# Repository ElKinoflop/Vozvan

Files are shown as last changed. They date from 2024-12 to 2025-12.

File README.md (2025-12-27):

# Vozvan
Stacked acrylic, handwired, monobody split, 12.75u, 40% keyboard

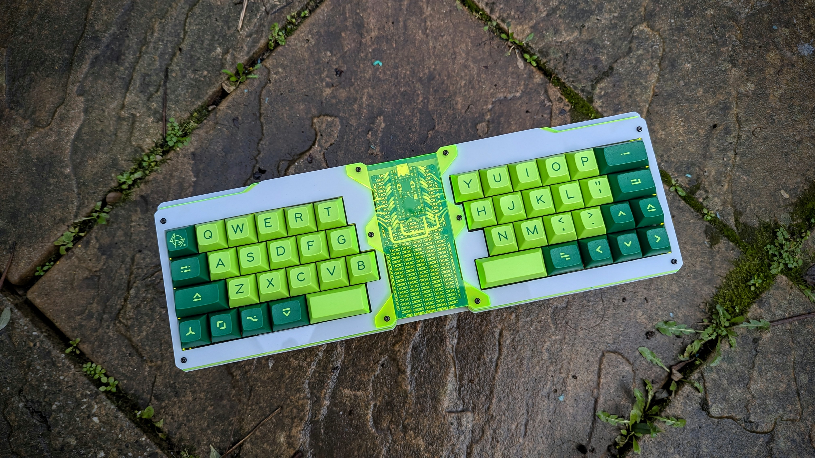
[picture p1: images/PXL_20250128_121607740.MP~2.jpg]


Vozvan Keyboard Photo

Stacked acrylic keyboard case designed for handwiring with a <a href="https://mechboards.co.uk/products/pro-micro-5v?_pos=2&_sid=c64ff0323&_ss=r" target="_blank">Pro Micro footprint RP2040 controller</a>. 12.75u layout monobody split. Inspired by Peej's <a href="https://github.com/peej/lumberjack-keyboard" target="_blank">Lumberjack</a>, SquashKB's <a href="https://www.instagram.com/squash_kb/?hl=en-gb">Lesovoz</a>, Trashman's <a href="https://trashman.wiki/keyboards/v4n4g0n">V4N4G0N/Minivan</a> and <a href="https://p3dstore.notion.site/P3Dstore-Open-Source-Project-List-6e85900337294e769fb7b8fa68d68f27">Jake/P3D's acrylic cases</a>. The idea was to use all off the shelf components (other than the case). There are lots of options on what you could do with the central section such as encoders, tactile push buttons, LEDs or an OLED display. Different proto board mounts and either a straight or V shape can be accomodated by changing some of the layers.

Feel free to do whatever you want with the files. If you have any questions just ask (Discord username elkinoflop) and if you make one then share a photo with me!

<h1>Layout</h1>
There are two different layouts. A stabless version and a version which requires 2x plate mounted 2u stabs. They both have the same amount of keys so your choice of layout doesn't change the matrix.

<h2>Stabless</h2>
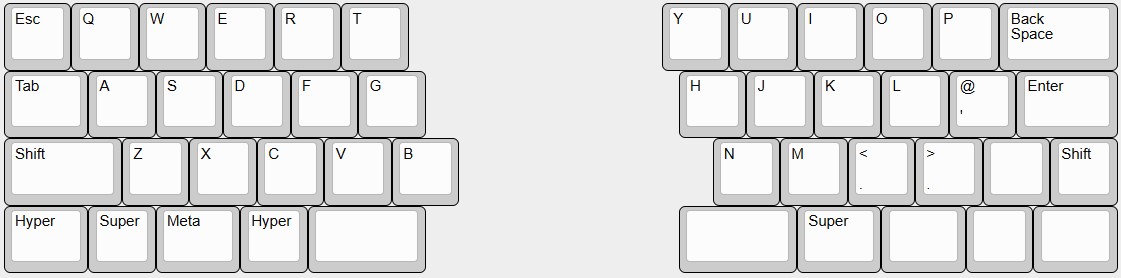
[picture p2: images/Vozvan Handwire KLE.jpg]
Vozvan Stabless KLE Image


<h2>Stabbed</h2>
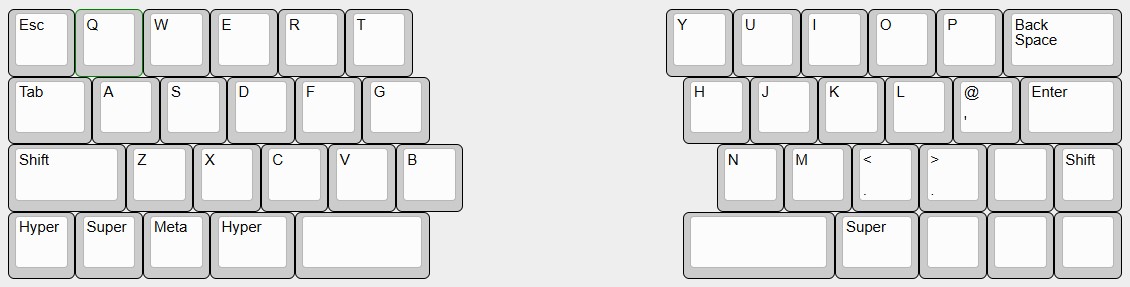
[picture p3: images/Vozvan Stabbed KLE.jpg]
Vozvan Stabbed KLE Image


<h1>KLE Raw Data</h1>
<h2>Stabless</h2>
["Esc","Q","W","E","R","T",{x:3.75},"Y","U","I","O","P",{w:1.75},"Back<br>Space"],
[{w:1.25},"Tab","A","S","D","F","G",{x:3.75},"H","J","K","L","@\n'",{w:1.5},"Enter"],
[{w:1.75},"Shift","Z","X","C","V","B",{x:3.75},"N","M","<\n.",">\n.",{a:7},"",{a:4},"Shift"],
[{w:1.25},"Hyper","Super",{w:1.25},"Meta","Hyper",{a:7,w:1.75},"",{x:3.75,w:1.75},"",{a:4,w:1.25},"Super",{a:7,w:1.25},"","",{w:1.25},""]

<h2>Stabbed</h2>
["Esc","Q","W","E","R","T",{x:3.75},"Y","U","I","O","P",{w:1.75},"Back<br>Space"],
[{w:1.25},"Tab","A","S","D","F","G",{x:3.75},"H","J","K","L","@\n'",{w:1.5},"Enter"],
[{w:1.75},"Shift","Z","X","C","V","B",{x:3.75},"N","M","<\n.",">\n.",{a:7},"",{a:4},"Shift"],
["Hyper","Super","Meta",{w:1.25},"Hyper",{a:7,w:2},"",{x:3.75,w:2.25},"",{a:4,w:1.25},"Super",{a:7},"","",""]

<h1>Case variants</h1>
<li>There are different variations of the case. Layers 1-7 are common across all variants (except the one piece) but 0 (component cover), 8 (bottom) and 9 (feet) will change depending on which you choose. Currently only the SEC version has been tested. If you do add an encoder or extra buttons in the centre remember to modify the central component cover so that they fit. There are some STL 3D models in the <a href="https://github.com/ElKinoflop/Vozvan/tree/main/images" target="_blank">images folder</a>, these are just to give an alternative visualisation of the case and not designed for printing.</li>
<h3>Standard - ElectroCookie</h3>
Straight board with mounting points for an ElectroCookie protoboard. The specific case files for this variant will have SEC after the layer number

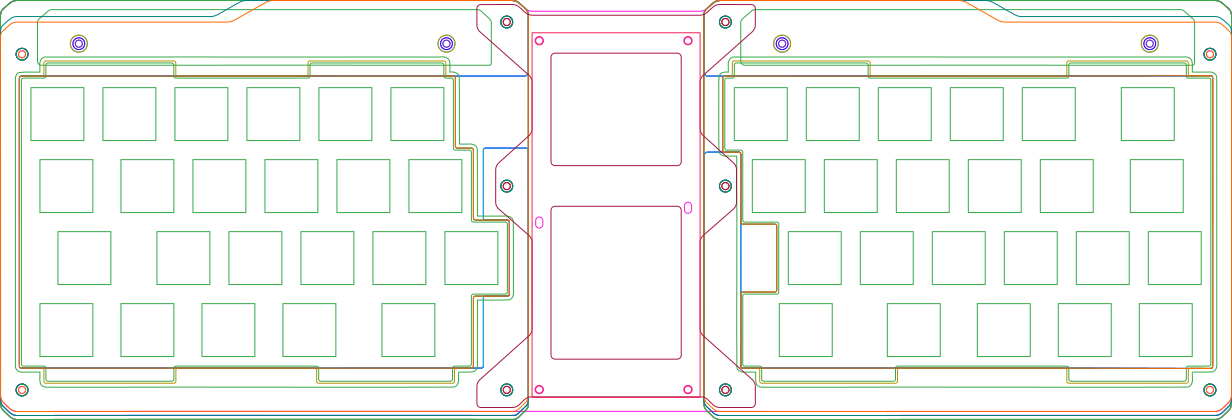
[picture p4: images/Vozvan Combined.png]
Vozvan SEC Case Layers


<h3>Standard - FeatherWing</h3>
Straight board with mounting points for an Adafruit FeatherWing. The specific case files for this variant will have SFW after the layer number

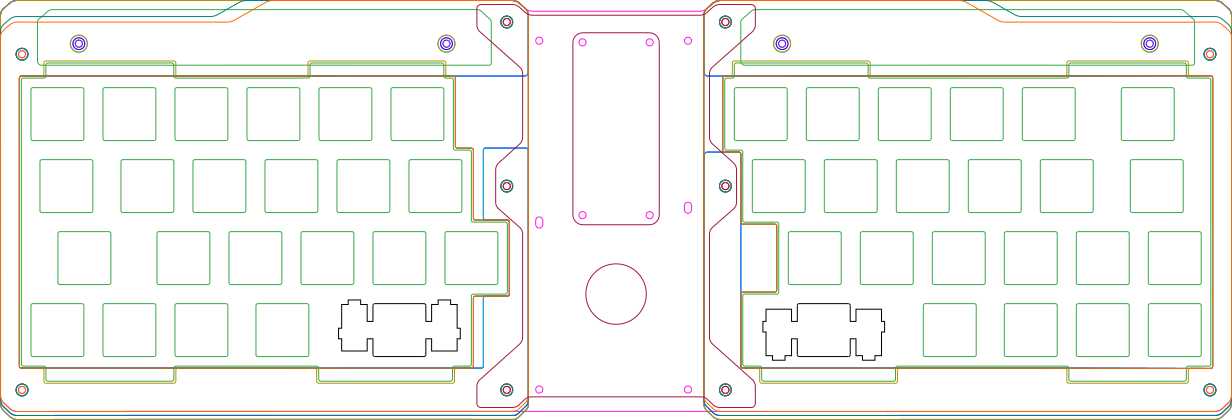
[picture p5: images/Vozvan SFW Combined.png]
Vozvan SFW Case Layers


<h3>5 Degree V - ElectroCookie</h3>
5 Degree V board with mounting points for an ElectroCookie protoboard. The specific case files for this variant will have VEC after the layer number

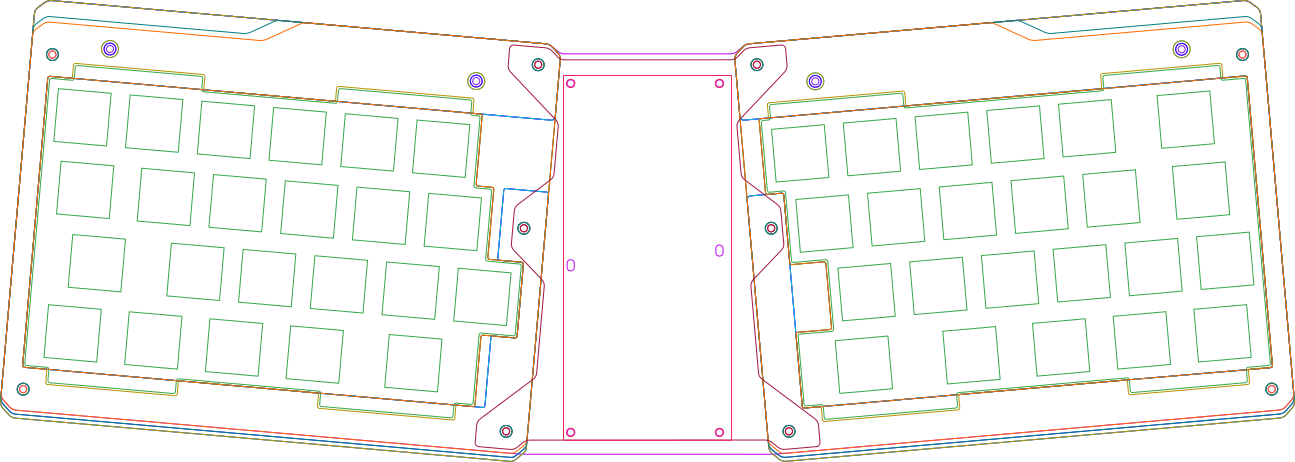
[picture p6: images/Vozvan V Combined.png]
Vozvan VEC Case Layers


<h3>5 Degree V - FeatherWing</h3>
5 Degree V board with mounting points for an Adafruit FeatherWing. The specific case files for this variant will have VFW after the layer number. 'Vozvan 0VFW - Component Cover Button 16mm.dxf' has a cutout designed to be used with an Adafruit NeoPixel FeatherWing and a push button (16mm diameter hole).

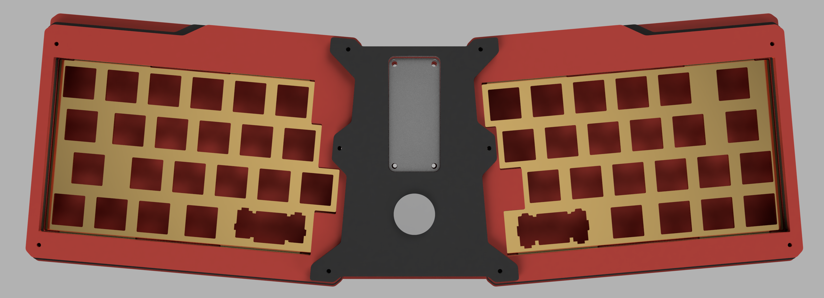
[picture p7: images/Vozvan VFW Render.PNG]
Vozvan VFW Case Render


<h3>One Piece - 5 Degree V - FeatherWing</h3>
A more enclosed variant, 5 Degree V board with mounting points for an Adafruit FeatherWing only. Other than the plates and feet the case parts aren't compatible with the other variants. '0VFWOP - Centre Cover.dxf' has a cutout designed to be used with a push button (16mm diameter hole). You need one of each DXF in the <a href="https://github.com/ElKinoflop/Vozvan/tree/main/Case%20Files/One%20Piece%20VFW" target="_blank">One Piece VFW</a> folder.

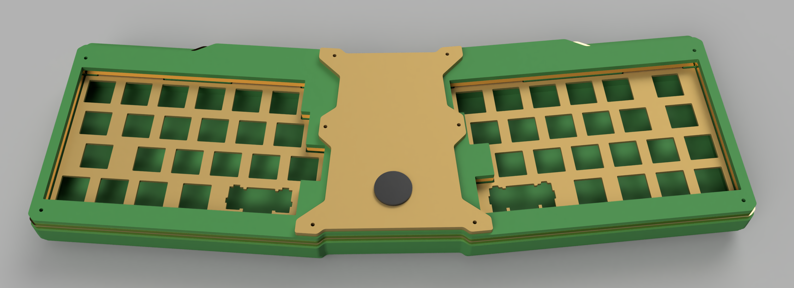
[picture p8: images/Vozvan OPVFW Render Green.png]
Vozvan OPVFW Case Render


<h1>Case Manufacturing</h1>
<ul>
  <li><a href="https://github.com/ElKinoflop/Vozvan/tree/main/Case%20Files" target="_blank">Case files</a></li>
  <li>Designed to be cut from 3mm acrylic</li>
  <li>With the open case layers (5,6 & 7) there is the option of positioning some of the smaller parts (layers 0 or 9) within the open section to save some acrylic but some fabricators might not like doing this.</li>
  <li>Note that acrylic sheets can vary in thickness even if they are listed as 3mm. I have found that Perspex® typically measures at 3-3.1mm whereas Xintao (which most Chinese suppliers seem to use) typically comes in at 2.6-2.7mm. This doesn't matter too much except for your switches will be much more visible with thinner sheets.</li>
  <li>As a rough idea of cost <a href="https://mechboards.co.uk/" target="_blank">Mechboards.co.uk</a> was the best price I could find in the UK at around £80-£90 (inc VAT) for the case and plate. This will vary depending on what acrylic you choose</li>
  <li>Don't force the standoffs through if you find some of the standoffs too tight. Use a small round file if you need to slightly widen any holes. The small round file from Draper 'Soft Grip Needle File Set, 140mm (6 Piece) (83982)' is the perfect size. You shouldn't need to do this but there can be some manufacturing variance.</li>
</ul>

Vozvan Orbit Explosion

<h1>Bill of Materials</h1>
<ul>
  <li>One of each <a href="https://github.com/ElKinoflop/Vozvan/tree/main/Case%20Files" target="_blank">case layer</a> cut from 3mm acrylic. You need one of each number but you don't need for example both 8SEC and 8VEC.</li>
  <li>Either the stabless or stabbed plate DXF file cut from 1.5mm metal/carbon. Flexier/plastic plates aren't recommened as without a PCB you can bottom out the switches on the case and risk the switches popping out of the plate</li>
  <li><a href="https://mechboards.co.uk/products/pro-micro-5v?_pos=2&_sid=c64ff0323&_ss=r" target="_blank">Pro Micro footprint RP2040 controller</a></li>
  <li>M2 Standoffs with a outside diameter of 3mm. 4x 5-6mm for the feet, 10x 12-14mm for the main case, 6x 2-6mm for the proto board mounts. <a href="https://amzn.eu/d/8H1HG6Y" target="_blank">Amazon Standoffs</a></li></li>
  <li>M2 Hex socket button head bolts. Various lengths between 4-12mm. <a href="https://www.aliexpress.com/item/32969042589.html" target="_blank">AliExpress bolts</a></li>
  <li><a href="https://www.amazon.co.uk/dp/B08151V9TS?ref=ppx_yo2ov_dt_b_fed_asin_title" target="_blank">ElectroCookie PCB Prototype Board 3.8"x3.5"</a> OR <a href="https://www.adafruit.com/product/2884" target="_blank">FeatherWing Proto board</a>. Make sure you orient the board correctly before soldering. The ElectroCookie boards aren't symmetrical, the case is designed so the side with the curved corners is on the right (unlike some of the photos)</li>
  <li>Adhesive gasket material. 4mm width. I used 2mm thick gaskets but slightly thinner would be better.</li>
  <li>Wire! Solid core 22 AWG suggested</li>
  <li>46x MX Switches</li>
  <li>46x 1N4148 Diodes (plus any extras if you have buttons/encoders in the middle)</li>
  <li>8x small adhesive feet</li>
  <li>Optional - 2x 2u Plate Mount Stabilisers if you are making the stabbed layout</li>
  <li>Optional - WS2812B LEDs. There's enough pins on the controller to add some RGB if you want. I used two of the <a href="https://www.aliexpress.com/item/1005007273486672.html" target="_blank">5x5 version of these</a>. Placing them under the prototype board gives a nice effect.</li>
  <li>Optional - Rotary Encoder (EC11). There's enough pins on the controller to add and encoder if you want</li>
  <li>Optional - 12*12*7.3mm tactile push button(s). These fit into the breadboard if you want some extra button(s) in the middle</li>
  <li>Optional - <a href="https://www.amazon.co.uk/dp/B08RMQP6YP?ref=ppx_yo2ov_dt_b_fed_asin_title" target="_blank">1.25mm Molex PicoBlade connectors and wire</a>. I used these to connect the matrix to the central section so they can easily be disconnected if required</li>
<li>Optional - <a href="https://learn.adafruit.com/adafruit-neopixel-featherwing" target="_blank">Adafruit NeoPixel FeatherWing</a>. For the VFW variant.</li>
  
</ul>

<h1>Firmware</h1>
I used <a href="https://github.com/JanLunge/pog" target="_blank">POG</a>  to create <a href="https://github.com/KMKfw/kmk_firmware" target="_blank">KMK</a> firmware. POG makes creating firmware super simple but I might create QMK/VIAL firmware at some point!
I have included my firmware files (generated by POG). 

If you have wired up the matrix and connected it to the same controller pins as I have then you should be able to use my firmware. Install <a href="https://circuitpython.org/board/0xcb_helios/" target="_blank">Circuit Python</a> onto the controller first and then copy all the unzipped files from the <a href="https://github.com/ElKinoflop/Vozvan/blob/main/Firmware/Vozvan%20POG%20Firmware.zip" target="_blank">firmware zip</a> onto the drive.

<h1>Handwired Matrix</h1>
This is how I handwired the Matrix.
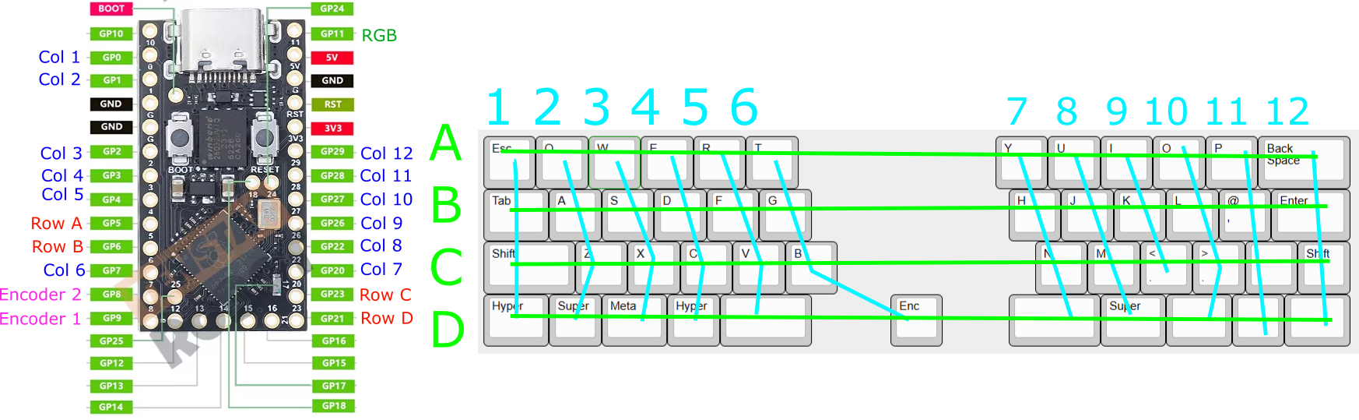
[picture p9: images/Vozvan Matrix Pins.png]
Vozvan Handiwired Matrix


An example of how to wire the proto board for an encoder
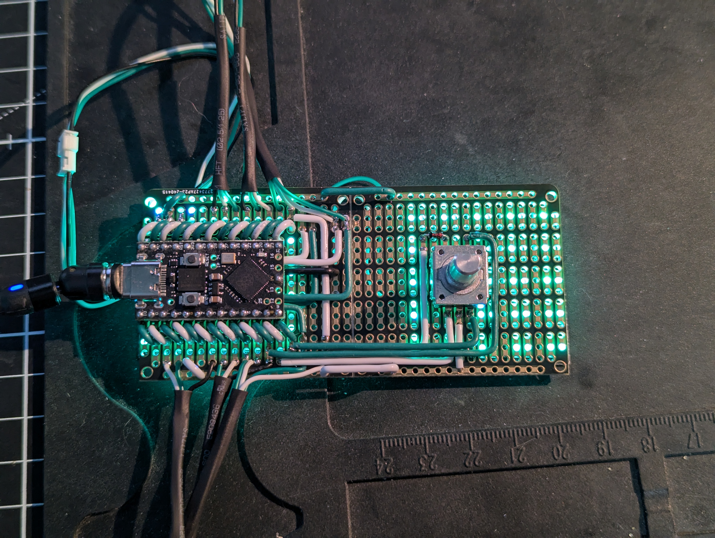
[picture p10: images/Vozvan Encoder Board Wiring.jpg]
Vozvan Encoder Board Wiring


<h1>Disclaimer</h1>
I have made a note of what variants of the case have been tested and which haven't. However you are ordering at your own risk and there are no guarantees that you end up with a functional item. If you do notice any mistakes please contact me (Discord username elkinoflop) so I can fix them.

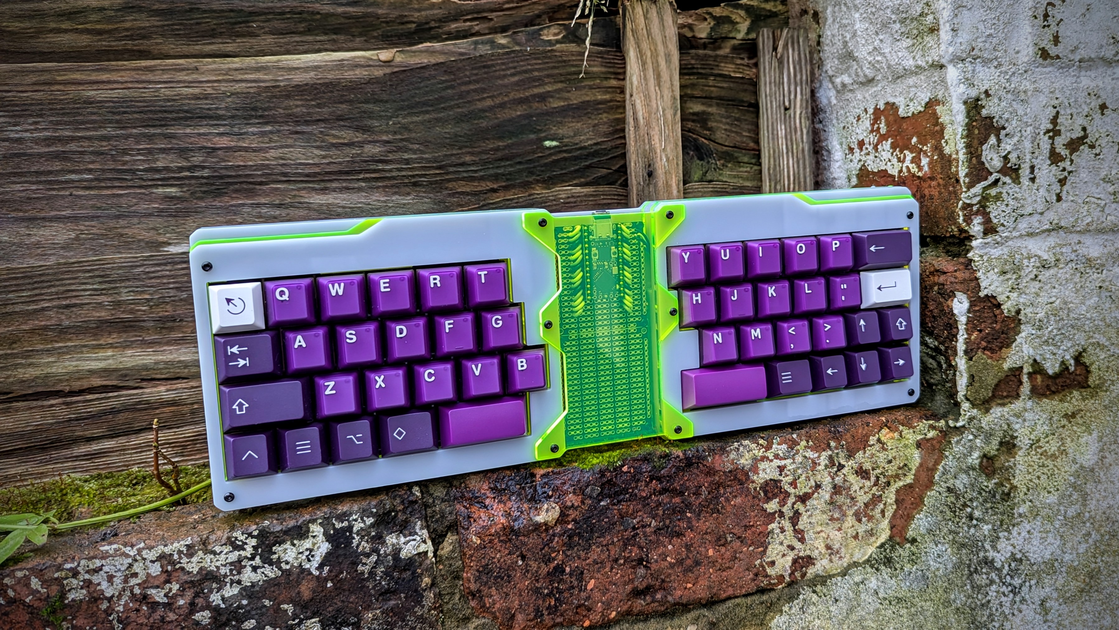
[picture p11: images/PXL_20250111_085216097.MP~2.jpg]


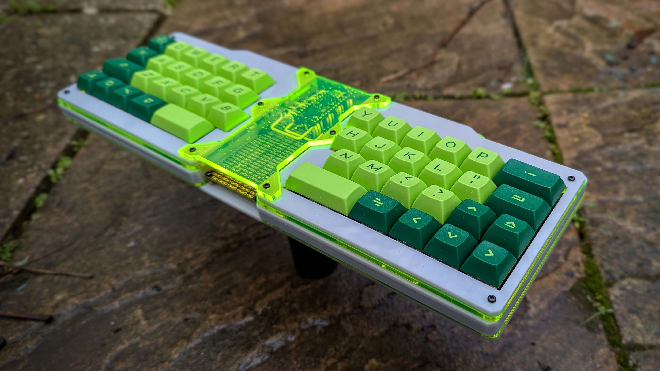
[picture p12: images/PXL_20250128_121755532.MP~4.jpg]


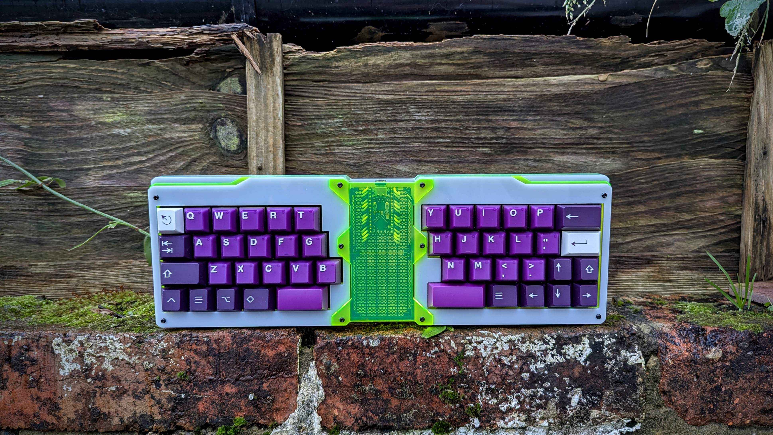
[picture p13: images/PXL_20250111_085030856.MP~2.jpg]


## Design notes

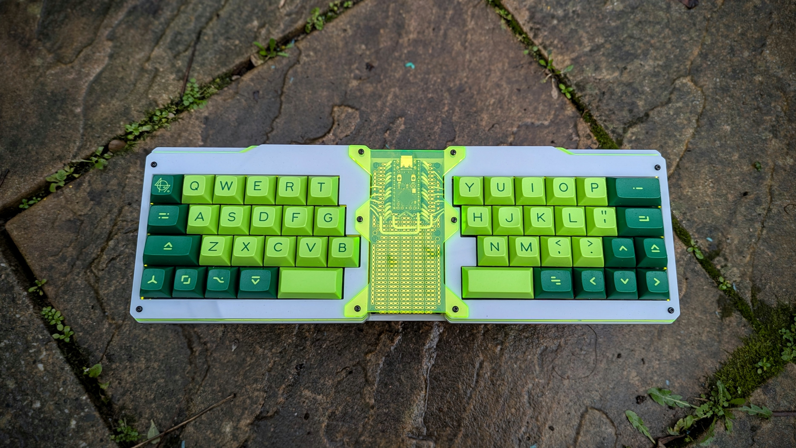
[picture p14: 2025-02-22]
images/PXL_20250128_121633707.MP~2.jpg

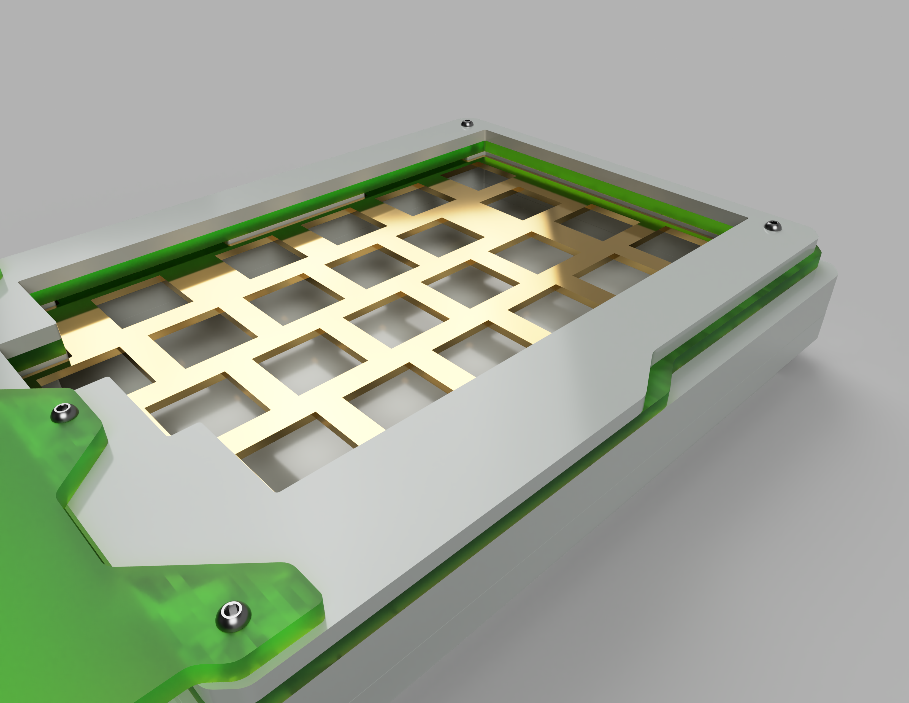
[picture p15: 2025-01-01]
images/9d9e7bed-2c7b-4b43-9d6c-c64e370a0fa1.PNG

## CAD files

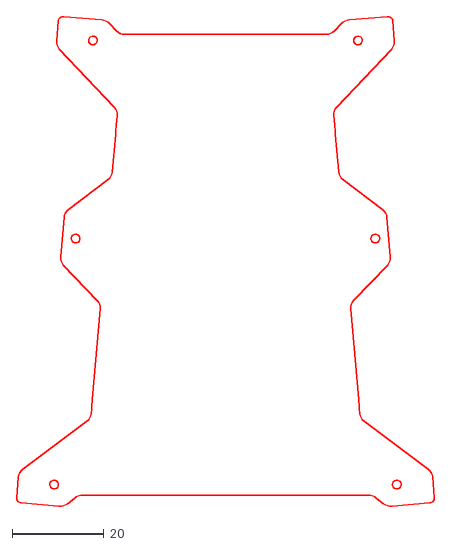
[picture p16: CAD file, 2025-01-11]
Case Files/Vozvan 0VEC 0VFW- Component Cover V Full.dxf
91.3 x 107.0

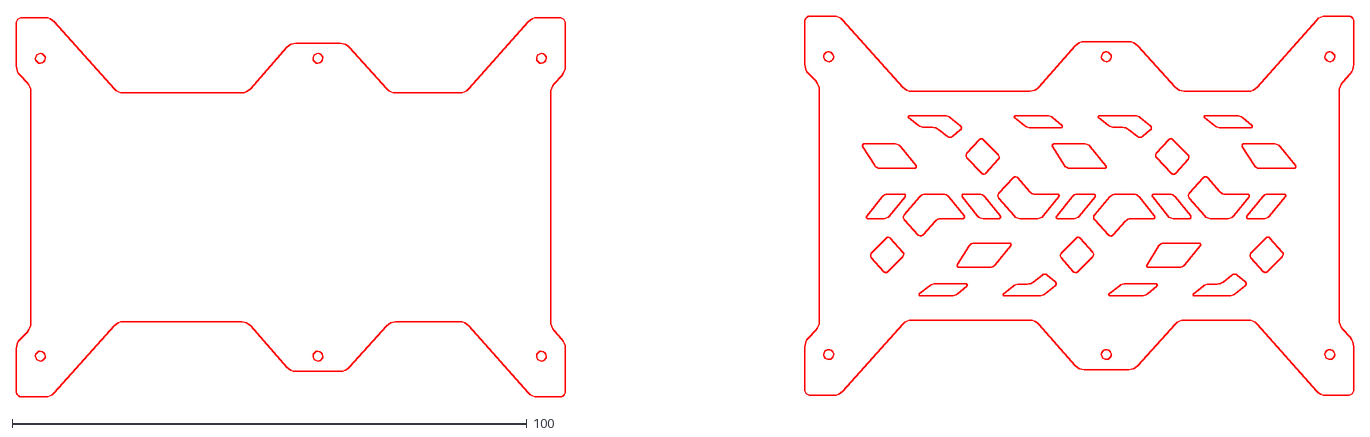
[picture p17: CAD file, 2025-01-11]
Case Files/Vozvan 0SEC 0SFW - Component Covers Full and Cint.dxf
259.8 x 74.0

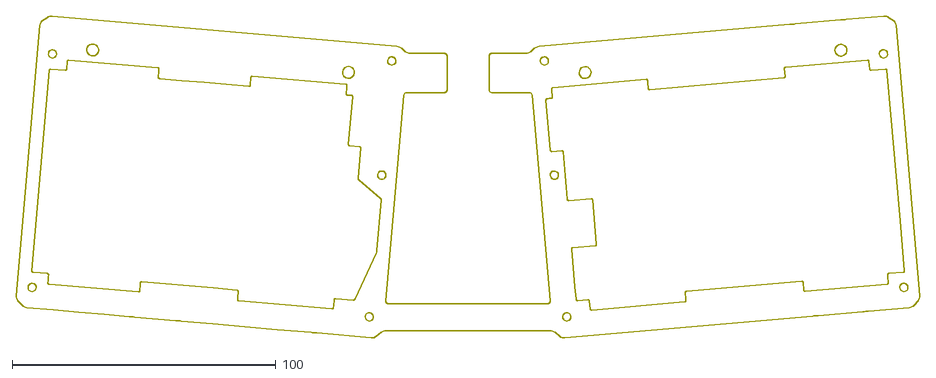
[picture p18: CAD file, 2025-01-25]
Case Files/One Piece VFW/4VFWOP - Plate Layer.dxf
342.4 x 122.0

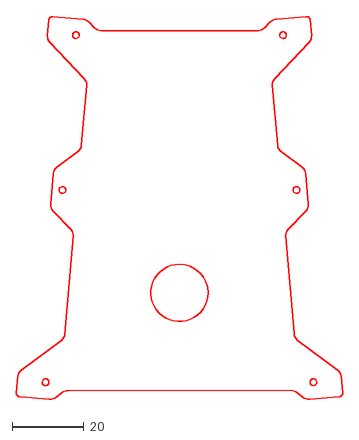
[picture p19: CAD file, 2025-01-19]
Case Files/Vozvan 0VEC 0VFW - Component Cover V Button 16mm.dxf
91.3 x 107.0

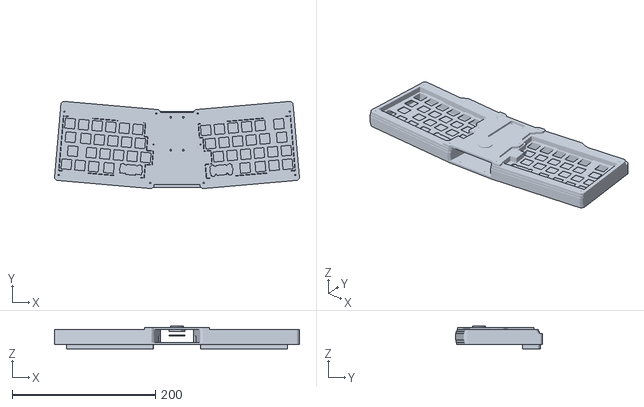
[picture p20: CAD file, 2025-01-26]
images/Vozvan VFW.stl
342.3 x 121.9 x 31.5

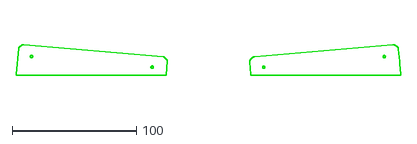
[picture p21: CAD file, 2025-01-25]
Case Files/One Piece VFW/9VFWOP - Foot VFWOP.dxf
309.0 x 24.8

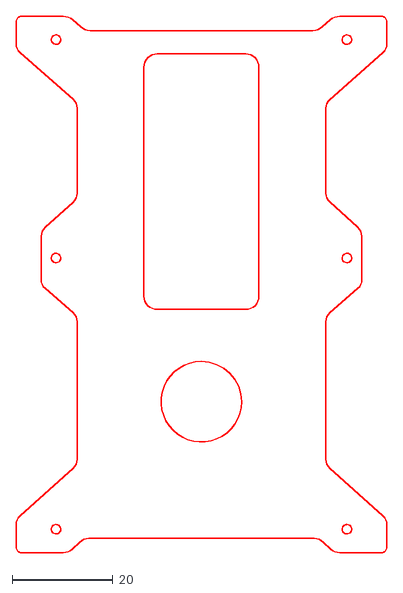
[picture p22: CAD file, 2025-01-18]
Case Files/Vozvan 0SFW - Component Cover FW Button 16mm.dxf
73.7 x 106.6

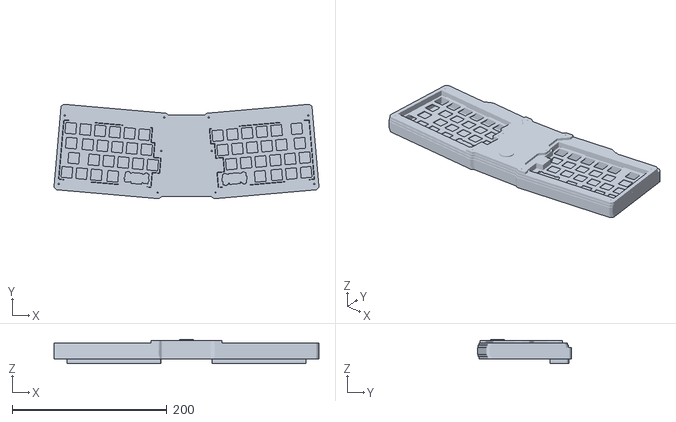
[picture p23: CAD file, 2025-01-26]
images/Vozvan One Piece.stl
342.3 x 121.9 x 31.5

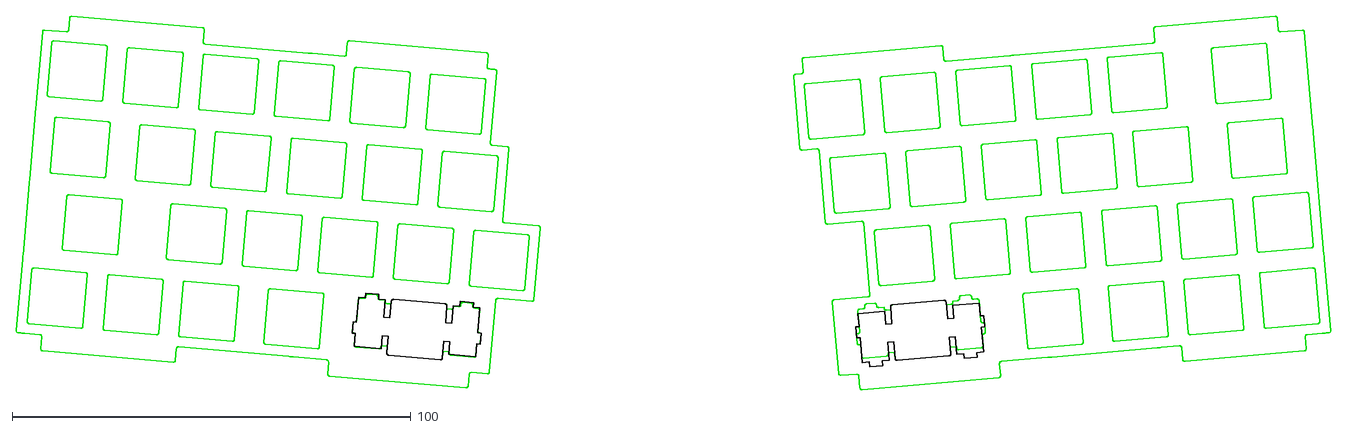
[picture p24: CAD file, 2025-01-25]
Case Files/One Piece VFW/3VFWOP - Plate Stabbed DNU.dxf
329.6 x 93.6

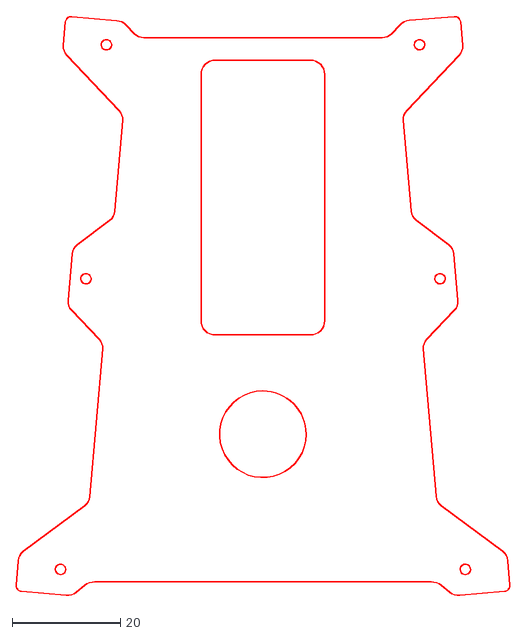
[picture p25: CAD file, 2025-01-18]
Case Files/Vozvan 0VFW - Component Cover Button 16mm.dxf
91.3 x 107.0

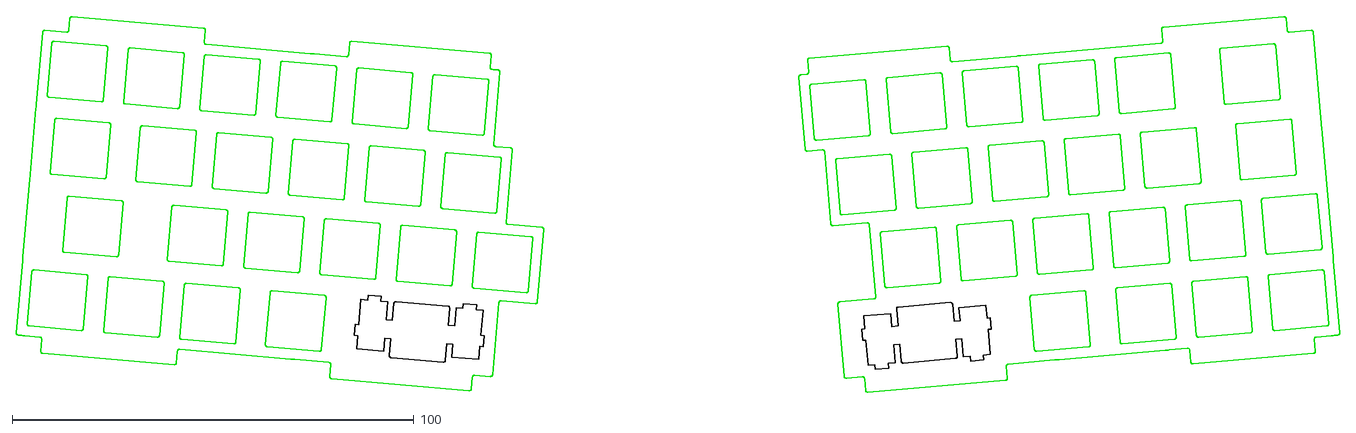
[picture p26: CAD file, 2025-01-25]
Case Files/One Piece VFW/3VFWOP - Plate Stabbed.dxf
329.6 x 93.6

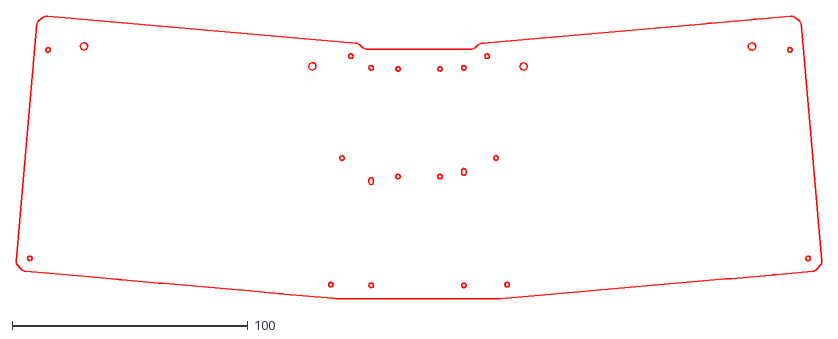
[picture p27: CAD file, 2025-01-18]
Case Files/Vozvan 8VEC 8VFW - Bottom.dxf
342.0 x 120.1

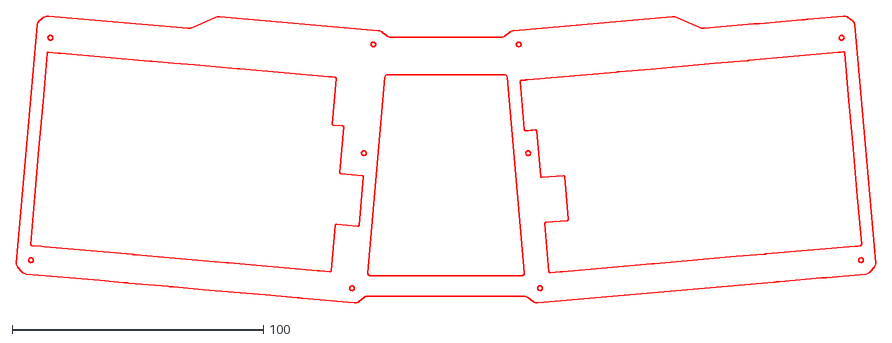
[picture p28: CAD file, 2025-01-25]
Case Files/One Piece VFW/1VFWOP - Top.dxf
342.0 x 114.2

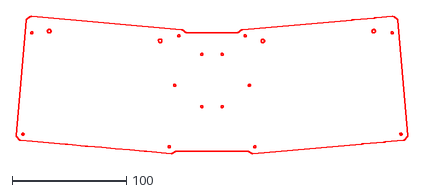
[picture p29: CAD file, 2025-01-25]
Case Files/One Piece VFW/8VFWOP - Bottom VFWOP.dxf
342.0 x 119.9

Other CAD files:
Case Files/Vozvan 2 - Accent.dxf
Case Files/One Piece VFW/0VFWOP - Centre Cover.dxf
Case Files/One Piece VFW/5VFWOP - Mid Upper.dxf
Case Files/One Piece VFW/2VFWOP - Accent.dxf
Case Files/One Piece VFW/6VFWOP - Mid Mid.dxf
Case Files/One Piece VFW/7VFWOP - Mid Lower.dxf
Case Files/Vozvan 1 - Top.dxf
Case Files/Vozvan 3 - Plate Stabless.dxf
Case Files/Vozvan 3B - Plate Stabbed.dxf
Case Files/Vozvan 4 - Plate Layer.dxf
Case Files/Vozvan 5 - Mid Upper.dxf
Case Files/Vozvan 6 - Mid Mid.dxf
Case Files/Vozvan 7 - Mid Lower.dxf
Case Files/Vozvan 8VEC - Bottom.dxf
Case Files/Vozvan 9SEC-SFW - Feet x4.dxf
Case Files/Vozvan 9VEC-VFW - Feet x4.dxf

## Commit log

2025-01-18 Rename Vozvan 0VEC - Component Cover V Full.dxf to Vozvan 0VEC 0VFW- Component Cover V Full.dxf
    [Vozvan 0VEC 0VFW- Component Cover V Full.dxf]
2025-01-18 Rename Vozvan 0SEC - Component Covers Full and Cint.dxf to Vozvan 0SEC 0SFW - Component Covers Full and Cint.dxf
    [Vozvan 0SEC 0SFW - Component Covers Full and Cint.dxf]
